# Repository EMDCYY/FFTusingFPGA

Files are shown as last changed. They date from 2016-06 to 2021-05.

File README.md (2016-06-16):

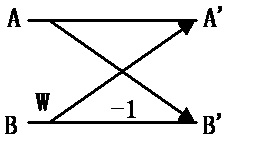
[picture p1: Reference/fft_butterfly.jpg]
  

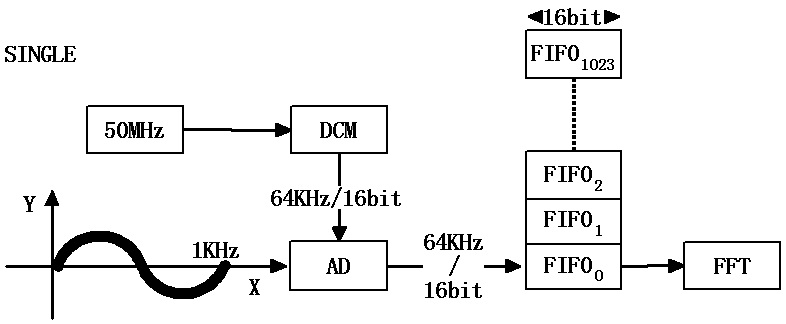
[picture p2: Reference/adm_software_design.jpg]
  

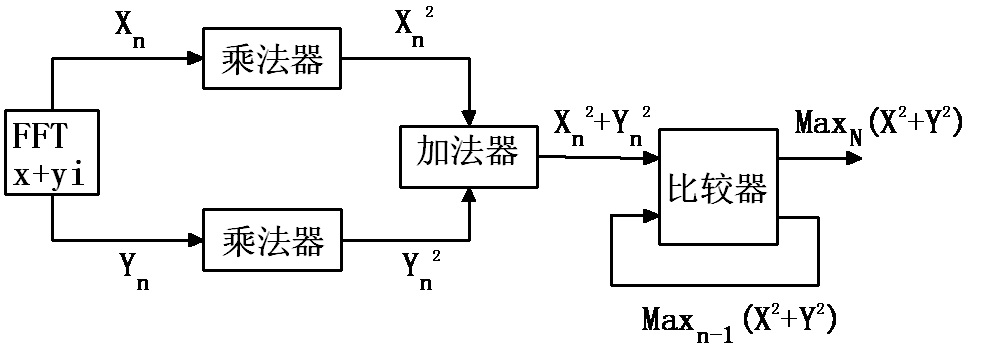
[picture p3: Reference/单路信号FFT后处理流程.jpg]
 

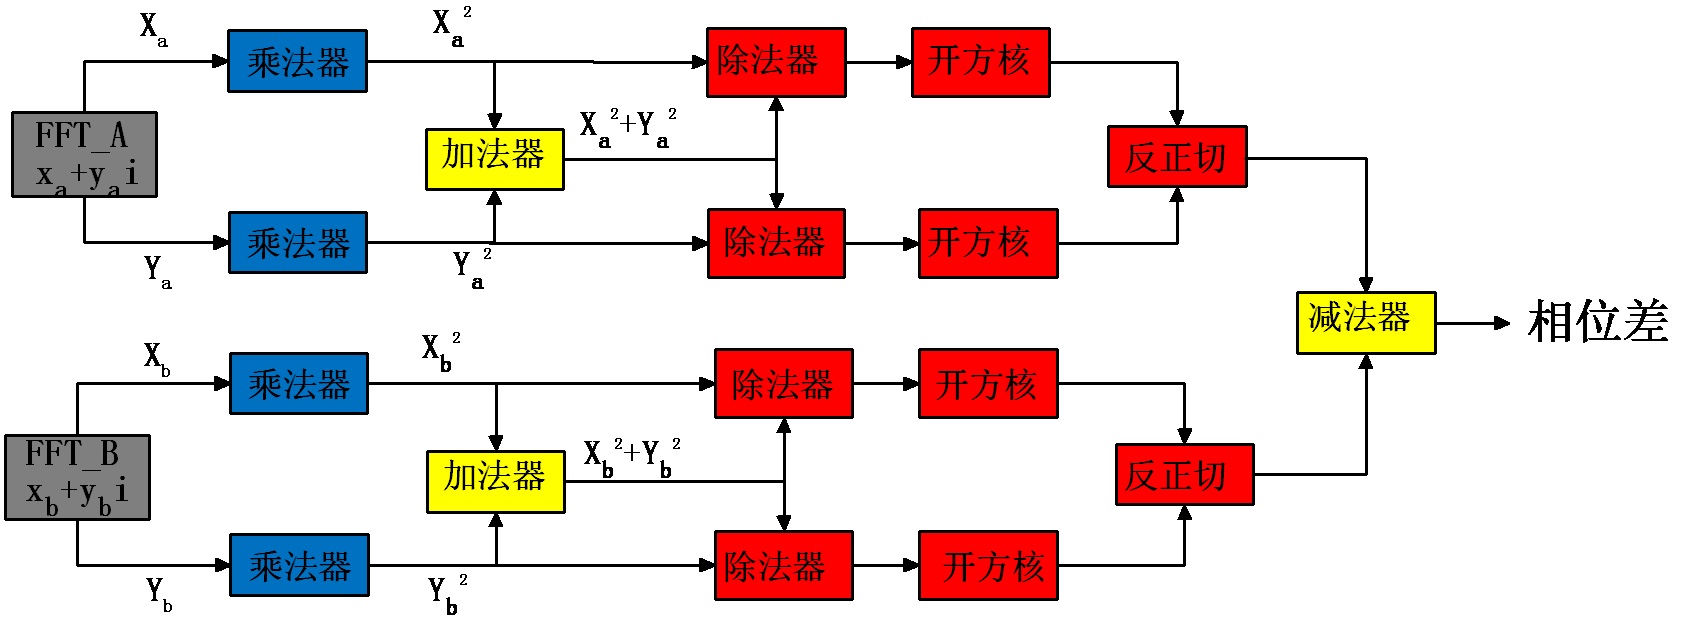
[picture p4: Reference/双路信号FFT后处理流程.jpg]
  

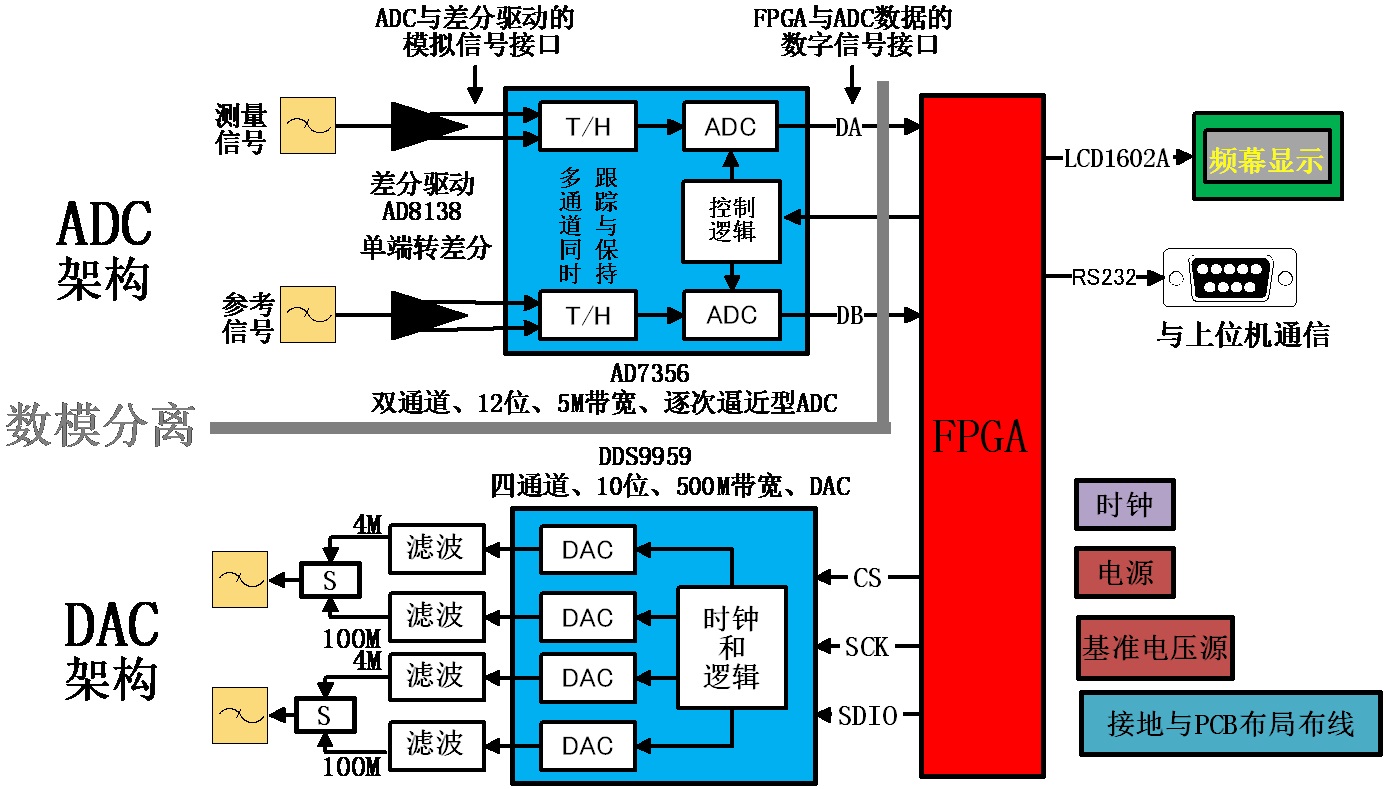
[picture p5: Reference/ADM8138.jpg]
   

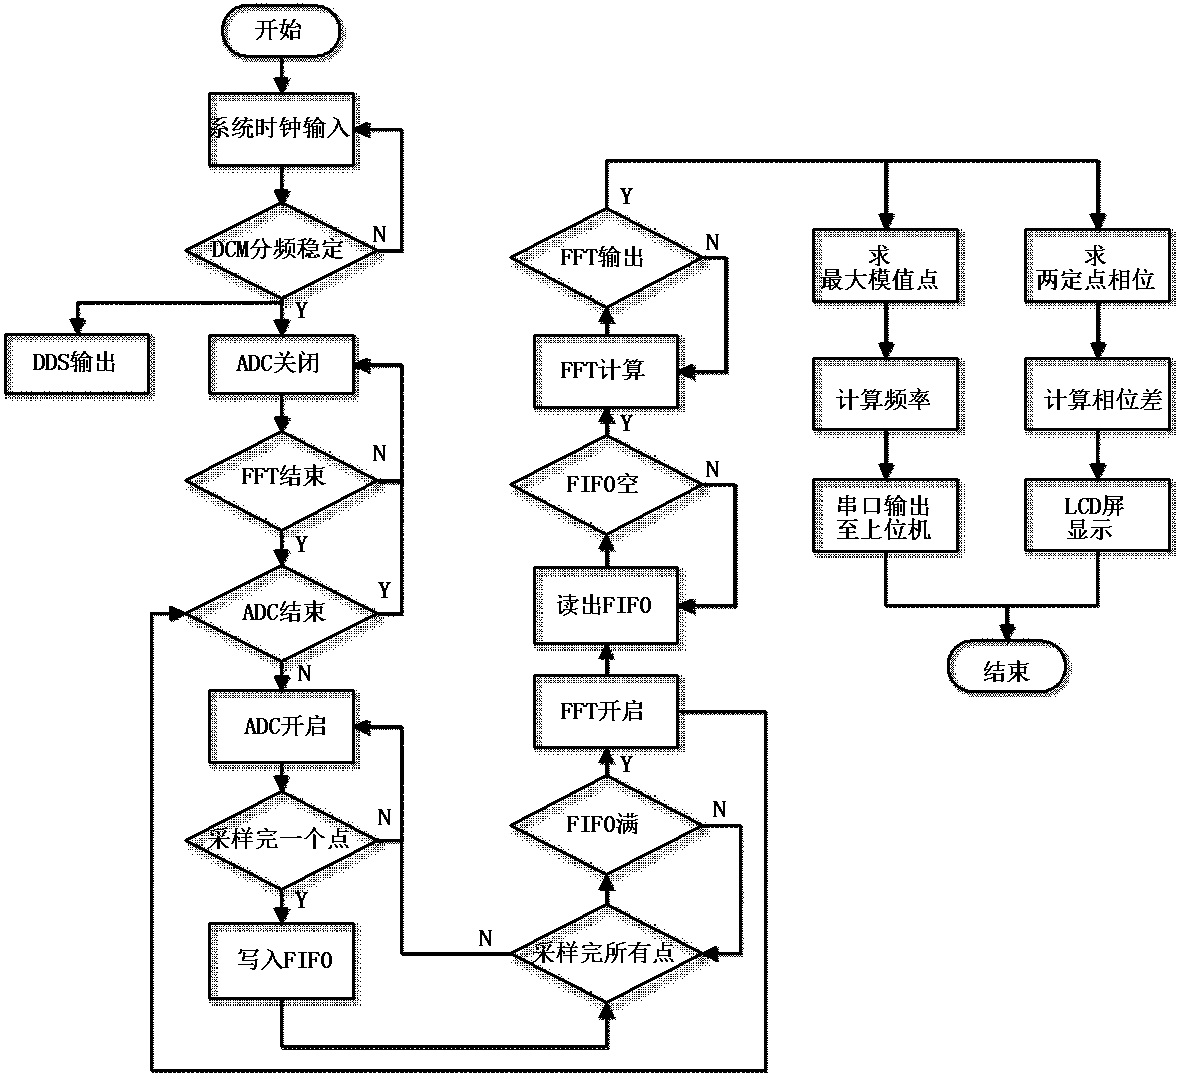
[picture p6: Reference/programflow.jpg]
  

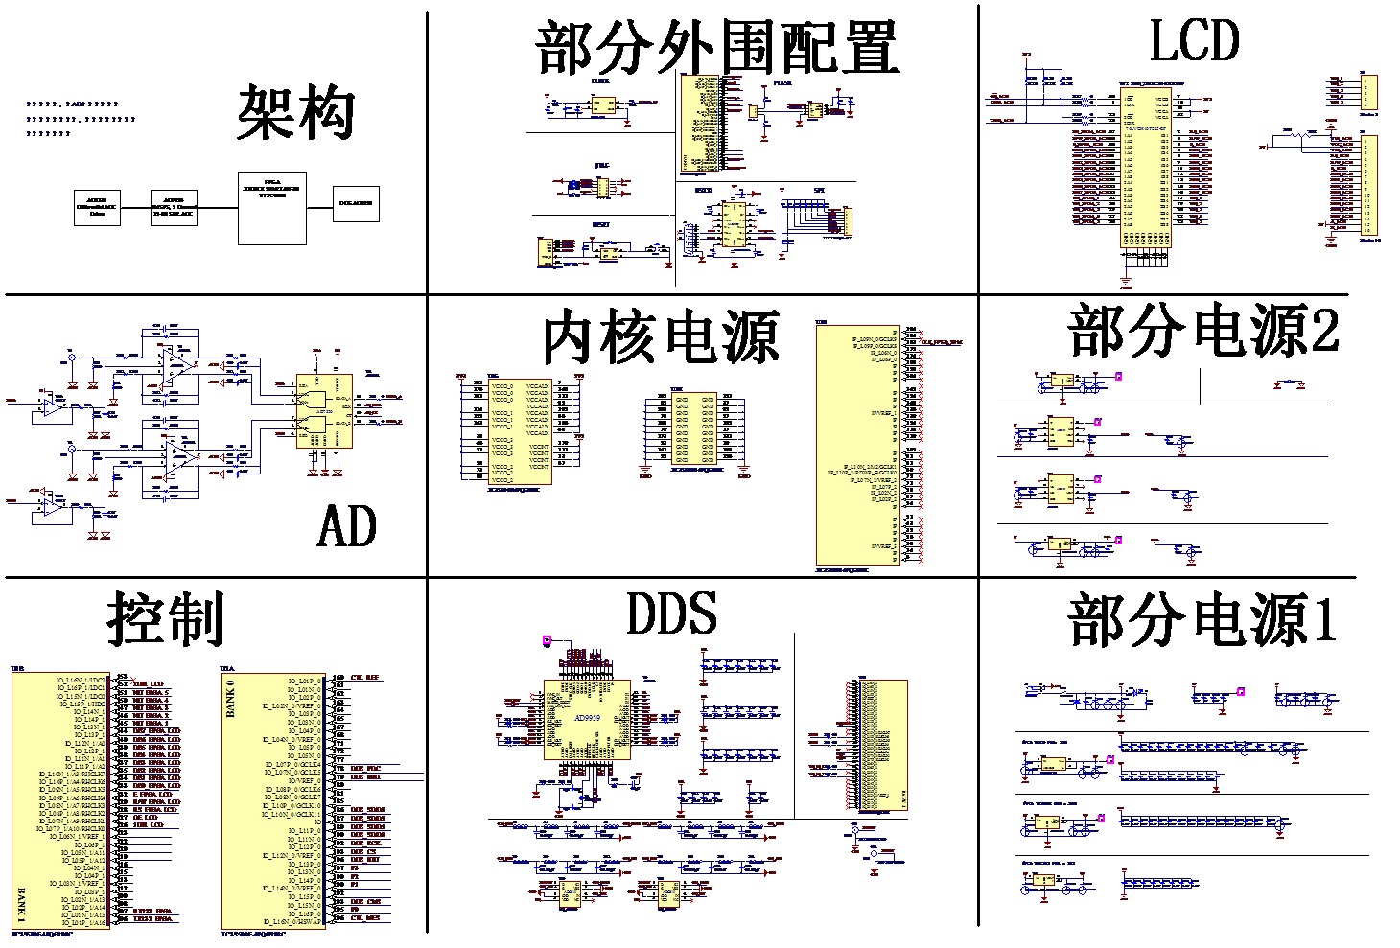
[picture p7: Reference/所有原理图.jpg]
  

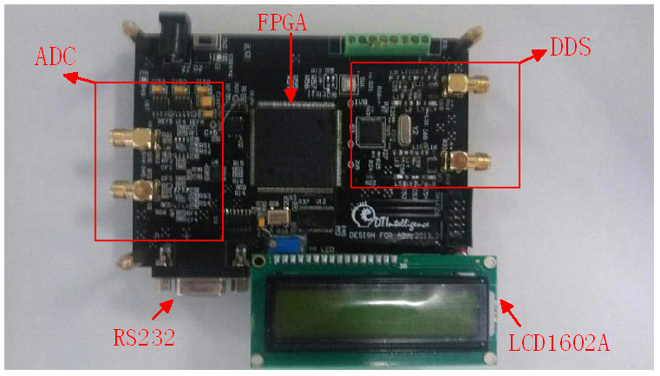
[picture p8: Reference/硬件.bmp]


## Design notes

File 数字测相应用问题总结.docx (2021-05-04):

# ADM数字测相技术问题归纳

刘鑫

2013.7.8

## 1. 功能概述

ADM数字测相由三部分功能组成：

①数字信号获取

②信号FFT处理

③求相位差计算

图1. ADM数字测相功能结构图

### 1.1 数字信号获取

数字信号获取的主要内容，是将两路正弦信号经AD同时采样转换成数字信号。本系统待测信号是两路频率为1KHz，峰-峰值为1Vp-p的双极性正弦波。通过MatLab仿真，若测相精度要达到千分之一个周期(1‰*2 π )，即测量绝对误差要在0.36°以内，需要选择转换速率在1.6M～3.2M之间、分辨率为10～12位的AD芯片。

#### 1.1.1 电路设计问题

这里选择AD7356是一款双12 bit、高速、低功耗的逐次逼近型（SAR）模数转换器（ADCC），采用2.5 V单电源供电，具有高达5 MSPS的吞吐率。该器件内置两个ADCC，各ADCC之前均配有一个低噪声、宽带宽采样保持电路，可处理110 MHz以上的输入频率。

但该器件是采用差分输入，其范围为共模±VRef/2。系统输入信号为单输入差分正弦信号，因此需要执行单端转差分转换。对AD7356进行差分驱动的理想方法是采用AD8138之类的差分放大器。该器件可以用作单端转差分放大器或差分转差分放大器。AD8138还能提供共模电平转换。实际电路图如下：

图2. 数字信号获取结构电路图

图2是参考AD器件生产商ADI公司提供文档“EVAL-AD7352/AD7356/AD7357”（见此附件16页）所绘。实际中，图2与文档参考电路图有区别，在于文档参考电路图差分驱动AD8138的V-端（1引脚）比图2多一个49R9端接电阻（如下图红线所标）。

图3. 文档参考电路图

问题1:

缺少的端接电阻对信号通过AD8138单端转差分的效果是否有影响？

#### 1.1.2 信号转换问题

两路正弦信号是由安捷伦脉冲函数发生器81150提供。设置参数如下：

①频率：1KHZ

②相位：1通道0°，2通道60°

③幅值：0.5V

④偏压：0V

两路信号如下图所示：

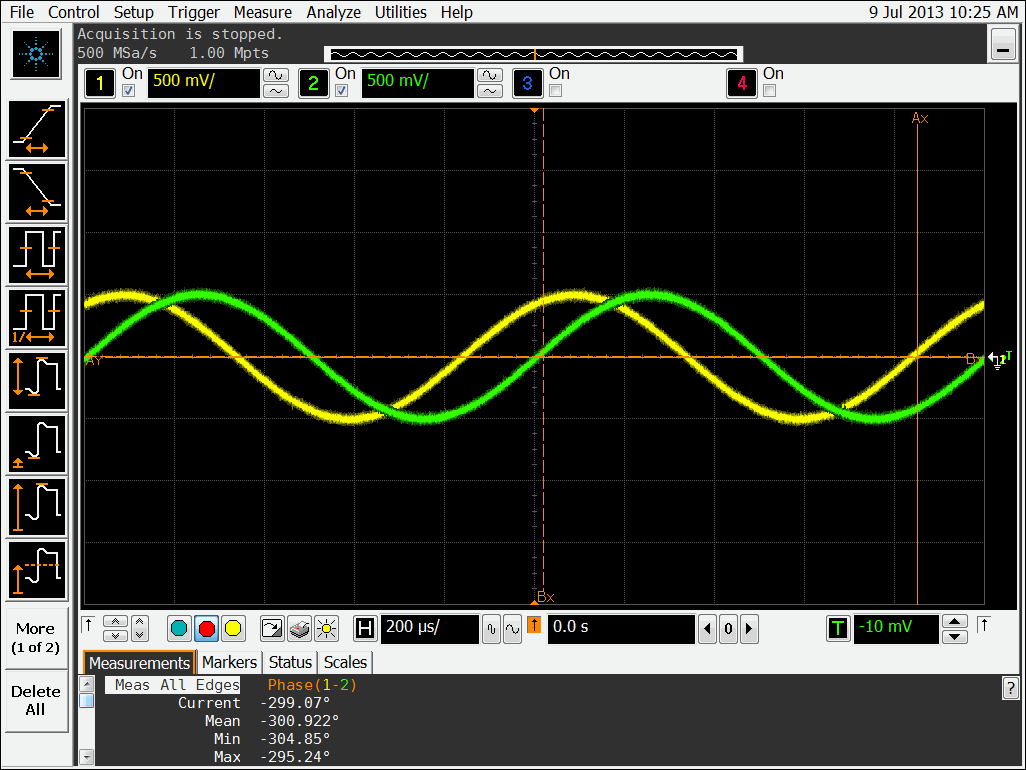
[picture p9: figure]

图4. 两路信号的设置

根据AD8138的参考使用效果,如下（亦见附件AD7356_cn第14页图20），

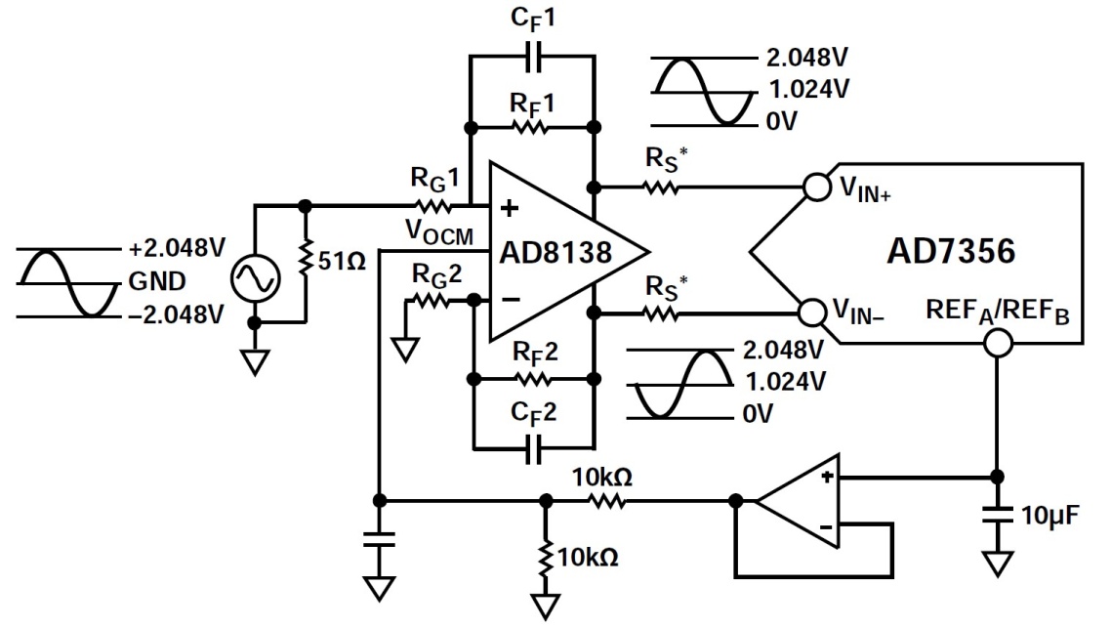
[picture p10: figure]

图5. AD8138参考使用效果

那么，1VP-P的正弦信号经过共模电平为1.25V的AD8138后，单端转差分的理论效果应如下图：

图6. 信号转变的理论效果

即，1VP-P正弦信号的转换效果：VP-P = 500mV，VOCM = 1.25V。

但实际的转换效果如下图，绿色为输入信号，其他为差分信号：

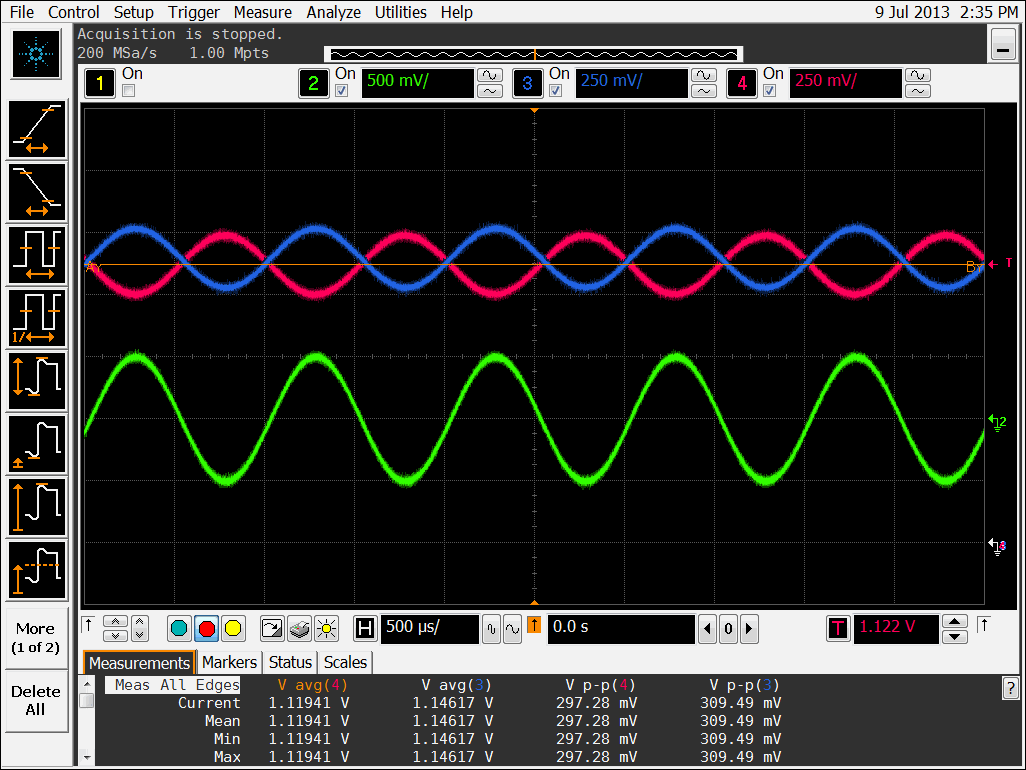
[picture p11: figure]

图7. 1VP-P正弦信号转换效果

1VP-P正弦信号的转换效果：VP-P = 300mV，VOCM = 1.13V。

峰峰值缩减是由于信号发生器输出端也有源电阻50Ω，再接与输入端接电阻49.9Ω分压，振幅缩减一半，交给AD8138处理的信号已变为500mVP-P，所以理论上，1VP-P正弦信号的转换效果应为VP-P = 250mV。

共模电平的降低或许与分压电阻R16、R17、R19、R20有关。虽然参考电路提供的分压电阻值是10KΩ，但在实际使用中发现，接地的10KΩ会与电路系统的阻值产生并联而降低阻值，所以实际中分压电阻选了较低的阻值50Ω。但高精度运放OP727的输入虽是2.5V，输出却是2.26V，经分压后成1.13V。

综上，既然输入端的端接电阻使得输入信号振幅减半，那么为了能使AD8138转换的是1VP-P正弦信号，就将信号发生器的信号源振幅增大一倍，即输入信号为2VP-P，转换结果如下图：

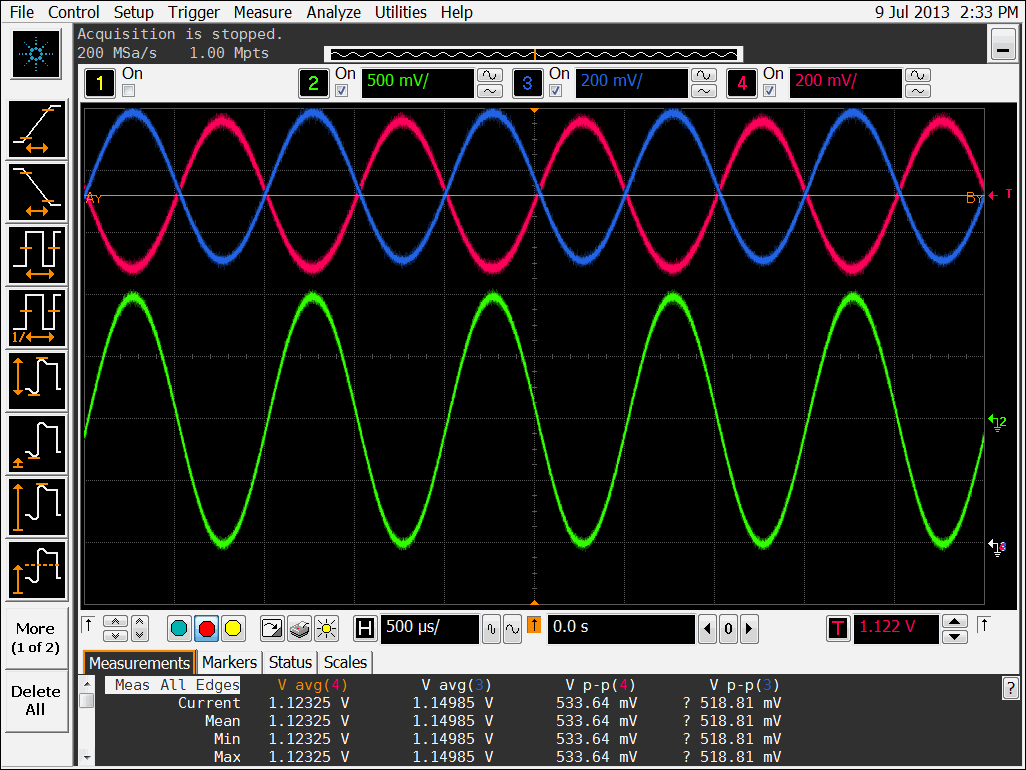
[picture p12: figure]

图8. 2VP-P正弦信号转换效果

2VP-P正弦信号的转换效果：VP-P = 0.5V，VOCM = 1.13V。符合理论值。

继续将信号发生器的输出信号振幅增大一倍，即输入信号为让4VP-P，转换结果如下图：

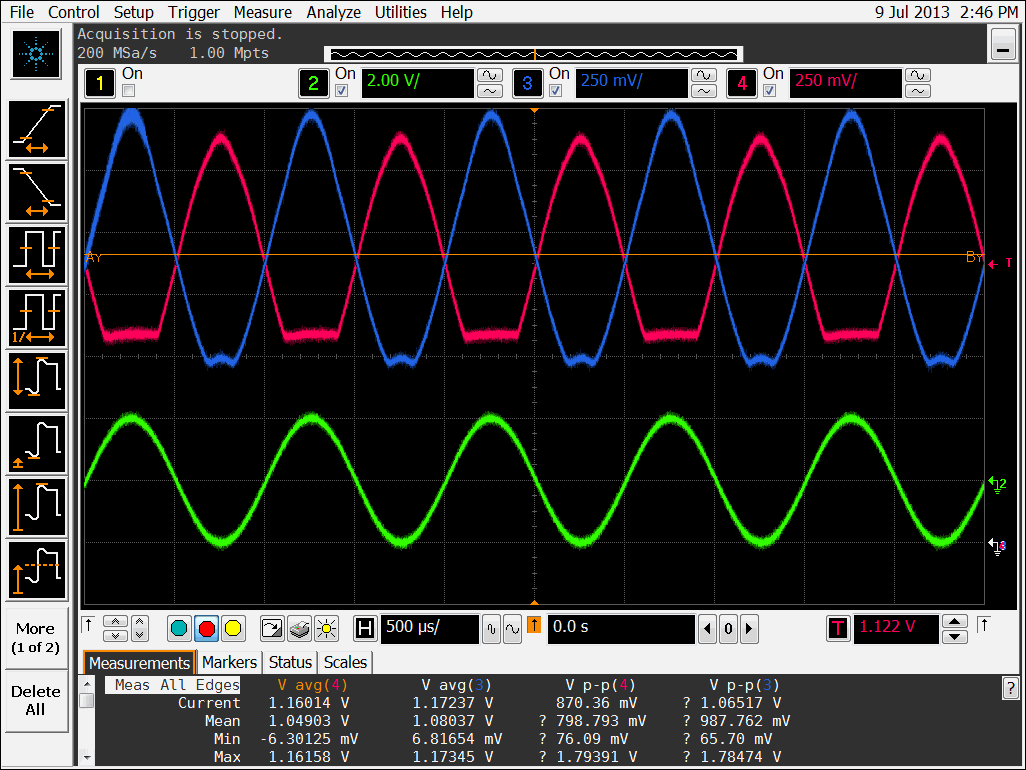
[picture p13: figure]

图9. 4VP-P正弦信号转换效果

之所以产生的差分信号在将近750mV~800mV之间出现截波，是因为我在设计时贪图单电源供电的方便，忽视了AD8138在单电源供电情况下的性能。图5中AD8138由±5V供电；当有单电源5V供电时，VOCM = 2.5V，输出电压最大摆幅是2.9V（见附件AD8138_cn第5页），即低电平截止电压为1V。

所以，虽然AD7356可以处理0V~2.5V电平范围内的信号，而且可以通过改变AD8138的反馈增益电阻RG1~4、RF1~4使得1VP-P输入信号转换为2.5VP-P差分信号，但由于本设计缺陷，使得差分信号只能局限1.5V~1V。

问题2：

实验证明，即使差分信号低电平被截止，FFT计算出该信号频率所对应的模值仍然最大。但是，低电平被截止是否影响求相位差，有何影响？下图白色波形为差分信号相减的结果。

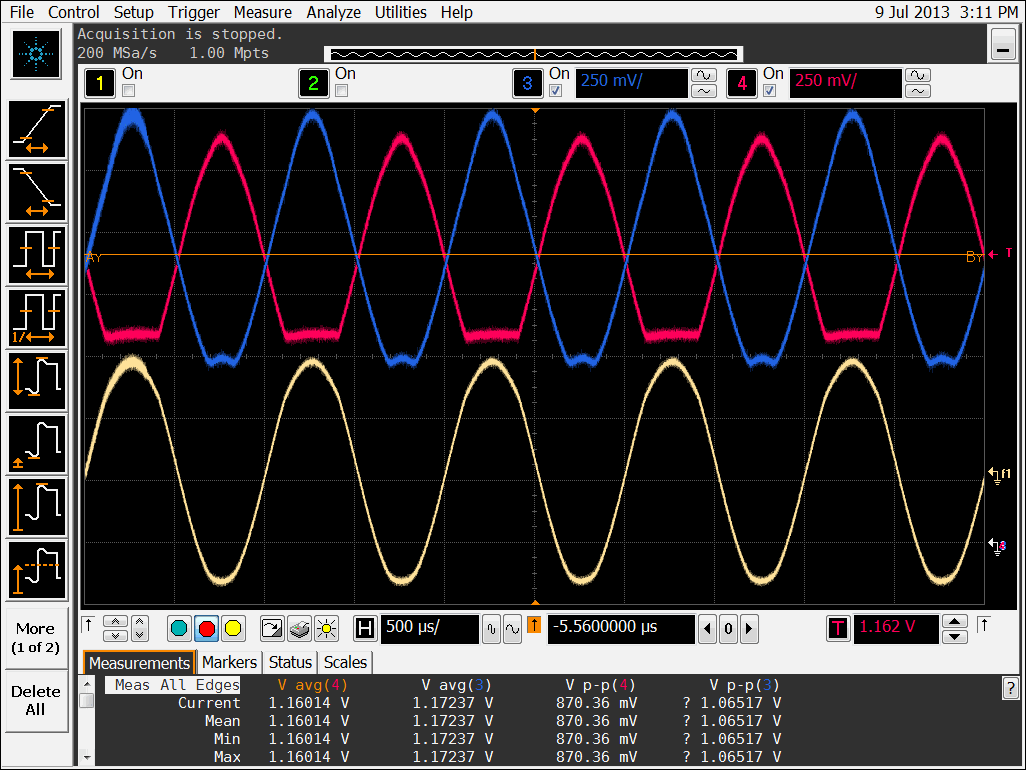
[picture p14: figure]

图10. 2VP-P正弦信号转换的差分信号相减

### 1.2 信号FFT处理

两路信号处理流程相同，且分别同时进行，如下图：

图11.信号处理流程图

FFT采用Xilinx提供的IP Core。通过串口将计算出的实部和虚部发送到上位机，用Excel处理，结果见附件。

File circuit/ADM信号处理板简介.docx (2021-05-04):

【产品名称】ADM信号处理平台

【产品功能】：

ADM信号处理平台采用XILINX SPARTEN-3E FPGA、高速AD7356和多通道直接数字频率合成器DDS9959作为平台芯片组。该平台可支持双路同时采样高达110 MHz的输入频率和四路同时输出高达500MHZ的标准正弦信号。

FPGA控制AD7356和DDS9959工作状态，并对采样信号进行FFT处理，将运算结果通过RS232或SPI传给上位机，或通过1602A显示。

# 【产品特色】

- 双路单端转差分高速运放驱动器
- 双路同时采样频率高达110MHZ
- 四路同时输出标准正弦波高达500MHZ
- 四路七阶巴特沃茨滤波器（默认分别为两组4MHZ和50MHZ）
- 具备RS232 \SPI \ 1602A

【主芯清单】：

# AD7356： 差分输入，双通道，同步采样，5 MSPS，12位SAR ADC

DDS9959：差分输出，四通道，同步输出，500MSPS，10位DAC

XC3S500E：XILINX FPGA，SPARTEN-3E FAMILY

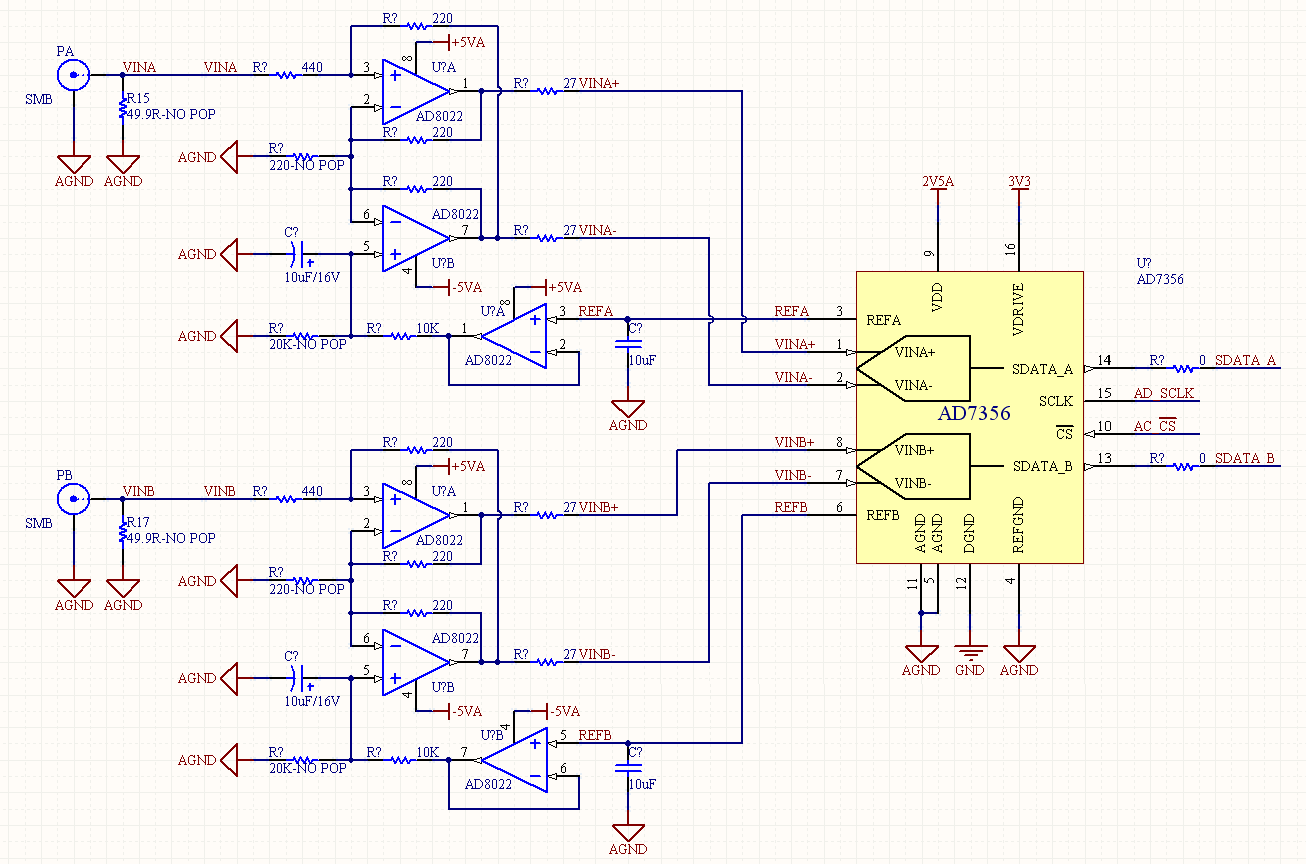
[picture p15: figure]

【FPGA电源】：

【AD7356电源】：

【数模隔离】

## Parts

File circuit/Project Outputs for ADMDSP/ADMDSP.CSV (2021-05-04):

Bill of Material for ADMDSP.PrjPCB
On 2013-3-4 at 20:25:52
Comment | Pattern | Quantity | Components
1V8 | MYTP | 1 | TP_9
2V5 | MYTP | 2 | TP_4, TP_8
3V3 | MYTP | 1 | TP_3
5V INPUT | IF_KLD-0202 | 1 | J2 | Low Voltage Power Supply Connector
5V | MYTP | 1 | TP_2
AD7356 | TSOP65P640X120-16N | 1 | U6 | Differential Input, Dual, Simultaneous Sampling, 5 MSPS, 12-Bit, SAR ADC
AD8138 | SOIC127P600X175-8N | 2 | U5, U8 | Low Distortion Differential ADC Driver
AD9959 | CP-56 | 1 | U9
ADR421 | SOIC127P600X175-8N | 2 | U16, U17 | Ultraprecision Low Noise, 2.048 V/2.500 V/ 3.00 V/5.00 V XFET? Voltage References
AS1117-2.5 | SOT223P700X180-4N | 1 | U14
BUS_74LVCH16T245-EP | TSSOP50P810X120-48N | 1 | U12
Cap Pol,100uF/25V,1210 | 1210[3528] | 7 | C86, C129, C131, C144, C146, C161, C169 | Polarized Capacitor (Radial)
Cap Pol,10uF/16V,1206 | 1206[3216] | 7 | C4, C150, C153, C157, C158, C167, C168 | Polarized Capacitor (Radial)
Cap Pol,10uF/25V,1206 | 1206[3216] | 14 | C62, C64, C66, C67, C72, C73, C74, C87, C88, C112, C130, C148, C155, C160 | Polarized Capacitor (Radial)
Cap Pol,150uF/15V,1206 | 7343 | 1 | C16 | Polarized Capacitor (Radial)
Cap Pol,22uF/25V,1210 | 1210[3528] | 1 | C145 | Polarized Capacitor (Radial)
Cap Pol,47uF/15V,1206 | 1210[3528] | 1 | C12 | Polarized Capacitor (Radial)
Cap,0.01nF/0603 | 1608[0603] - NoTopOverlay | 2 | C40, C48 | Capacitor
Cap,0.1uF/0603 | 1608[0603] | 78 | C1, C2, C3, C5, C6, C7, C8, C9, C10, C11, C13, C14, C15, C17, C45, C61, C63, C65, C68, C69, C70, C71, C75, C76, C77, C78, C79, C80, C81, C82, C83, C84, C85, C90, C91, C92, C93, C94, C95, C96, C97, C98, C99, C100, C113, C114, C115, C116, C117, C118, C119, C120, C121, C122, C123, C124, C125, C126, C127, C128, C136, C137, C138, C139, C140, C141, C142, C143, C147, C149, C151, C152, C154, C156, C159, C162, C163, C165 | Capacitor
Cap,0.1uF/0603 | 1608[0603] - NoTopOverlay | 27 | C18, C19, C20, C21, C22, C23, C24, C25, C26, C27, C28, C29, C30, C31, C32, C33, C34, C35, C36, C37, C38, C41, C42, C43, C44, C46, C47 | Capacitor
Cap,1.592nF/0603 | 1608[0603] - NoTopOverlay | 2 | C56, C59 | Capacitor
Cap,1uF/0805 | 2012[0805] | 2 | C164, C166 | Capacitor
Cap,39.693pF/0603 | 1608[0603] - NoTopOverlay | 4 | C49, C51, C52, C54 | Capacitor
Cap,39PF/0603 | 1608[0603] | 4 | CF1, CF2, CF3, CF4 | Capacitor
Cap,63.662pF/0603 | 1608[0603] - NoTopOverlay | 2 | C50, C53 | Capacitor
Cap,680pF/0603 | 1608[0603] - NoTopOverlay | 1 | C39 | Capacitor
Cap,992.315pF/0603 | 1608[0603] - NoTopOverlay | 4 | C55, C57, C58, C60 | Capacitor
D Connector 9 | DSUB1.385-2H9 | 1 | J1 | Receptacle Assembly, 9 Position, Right Angle
FAN1112 | SOT-223(FAN1112) | 1 | U15
Header 16 | HDR1X16 | 1 | P5 | Header, 16-Pin
Header 3 | HDR1X3 | 1 | P1 | Header, 3-Pin
Header 5 | HDR1X5 | 1 | P4 | Header, 5-Pin
Header 5X2 | 10Pin - JTAG | 1 | P2 | Header, 5-Pin, Dual row
Header 8 | 8PIN | 1 | P3 | Header, 8-Pin
Inductor,L0603,143.394nH | 2012[0805] - NoTopOverlay | 4 | L2, L3, L6, L7 | Inductor
Inductor,L0603,3.585uH | 2012[0805] - NoTopOverlay | 4 | L10, L11, L14, L15 | Inductor
Inductor,L0603,35.415nH | 2012[0805] - NoTopOverlay | 4 | L1, L4, L5, L8 | Inductor
Inductor,L0603,885.383nH | 2012[0805] - NoTopOverlay | 4 | L9, L12, L13, L16 | Inductor
LED | 2012[0805] - LED | 1 | D1
LM1117-1V8 | SOT223P700X180-4N | 1 | U19
LM1117-2V5 | SOT223P700X180-4N | 1 | U18
LM1117S-3.3 | TO-263-3SMD | 1 | U13
M25P80 | SOIC127P600X175-8N | 1 | U2
MAX3232CSE | NSO16 | 1 | U3
MAX811-EUS-T | SOT143 | 1 | U4
OP727 | SOIC127P600X175-8N | 1 | U7 | Precision Micropower Single-Supply Operational Amplifiers
P6SMBJ10A | SMBJ10A_DIOM4336X24N | 1 | D2 | Schottky Rectifier
REFA | MYTP | 1 | TP_6
REFB | MYTP | 1 | TP_7
Res Adj,20K | RES-adj | 1 | R41 | Tapped Resistor
Res,0R/0603 | 1608[0603] | 6 | R15, R18, R37, R38, R39, R40 | Resistor
Res,0R/0603 | 1608[0603] - NoTopOverlay | 4 | R54, R55, R56, R57 | Resistor
Res,0R/0805 | 1608[0603] - NoTopOverlay | 1 | R29 | Resistor
Res,0R/0805 | 2012[0805] | 1 | R43 | Resistor
Res,10K/0603,NoPoP | 1608[0603] | 2 | R52, R53 | Resistor
Res,10K/0603 | 1608[0603] | 14 | R5, R6, R14, R16, R17, R19, R20, R42, R46, R47, R48, R49, R50, R51 | Resistor
Res,10K/0805 | 1608[0603] | 2 | R12, R13 | Resistor
Res,1K/0805 | 1608[0603] | 4 | R8, R9, R10, R11 | Resistor
Res,1K/0805 | 1608[0603] - NoTopOverlay | 1 | R31 | Resistor
Res,2.2R/0805 | 1608[0603] | 2 | R2, R3 | Resistor
Res,33R/0603 | 1608[0603] | 4 | RS1, RS2, RS3, RS4 | Resistor
Res,4.7K/0603 | 1608[0603] | 3 | R34, R35, R36 | Resistor
Res,4.7K/0805 | 1608[0603] | 3 | R1, R4, R7 | Resistor
Res,49.9R/0805 | 1608[0603] - NoTopOverlay | 2 | R32, R33 | Resistor
Res,499R/0603 | 1608[0603] | 6 | RF1, RF2, RF3, RF4, RG1, RG4 | Resistor
Res,49R9/0603 | 1608[0603] | 2 | R44, R45 | Resistor
Res,50R/0805 | 1608[0603] - NoTopOverlay | 8 | R21, R22, R23, R24, R25, R26, R27, R28 | Resistor
Res,523R/0603 | 1608[0603] | 2 | RG3, RG6 | Resistor
Res,910R/0805 | 1608[0603] - NoTopOverlay | 1 | R30 | Resistor
SMB | SMB_V-RJ45 | 4 | CH1, CH2, V1, V2 | SMB Straight Connector
SW,EVQPLMA15_1 | PUSHBUTTONSW | 1 | SW1
SW_ADG619 | SOT23D | 2 | U10, U11 | Single SPDT Switches
SW-12D09 | SW_SD12D09 | 1 | SW2 | Single-Pole, Single-Throw Switch
TP_DDS_SYNC_CLK | MYTP | 1 | TP_1
XC3S500E-4PQG208C | PQG208_N | 1 | U1 | Spartan-3E 1.2V FPGA, 158 User I/Os, 208-Pin Pb-Free PQFP, Standard Performance, Commercial Grade
XTAL_25M | XTAL_DIP | 1 | Y2 | Crystal Oscillator
XTAL_50M | CRY_4Pin_50M | 1 | Y1

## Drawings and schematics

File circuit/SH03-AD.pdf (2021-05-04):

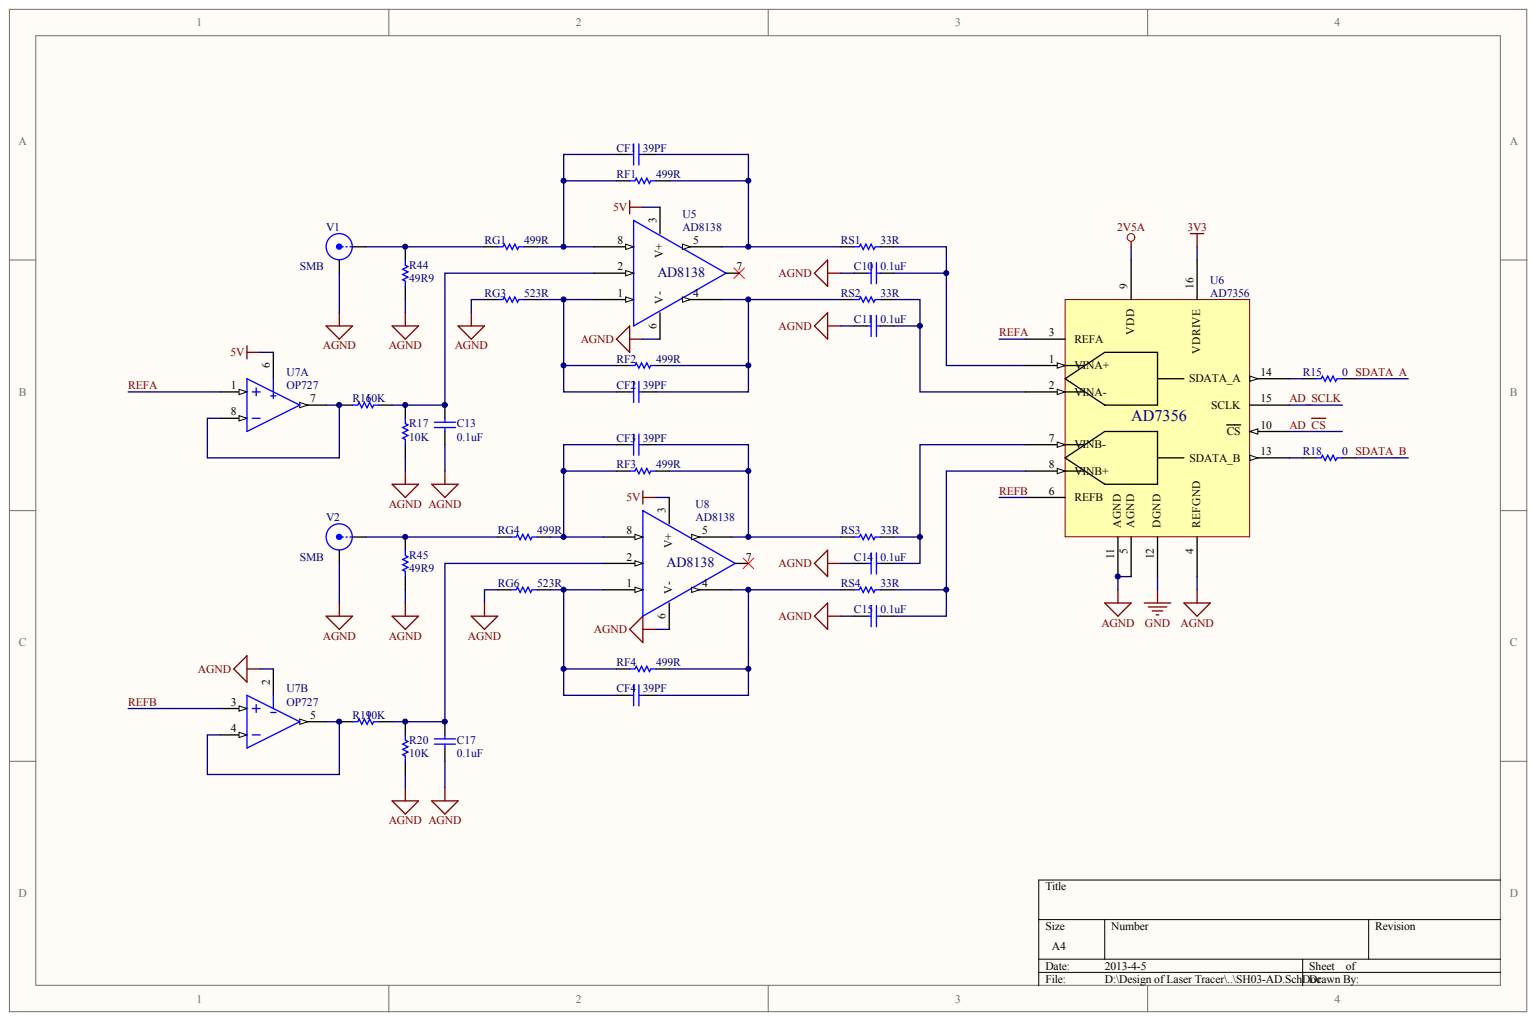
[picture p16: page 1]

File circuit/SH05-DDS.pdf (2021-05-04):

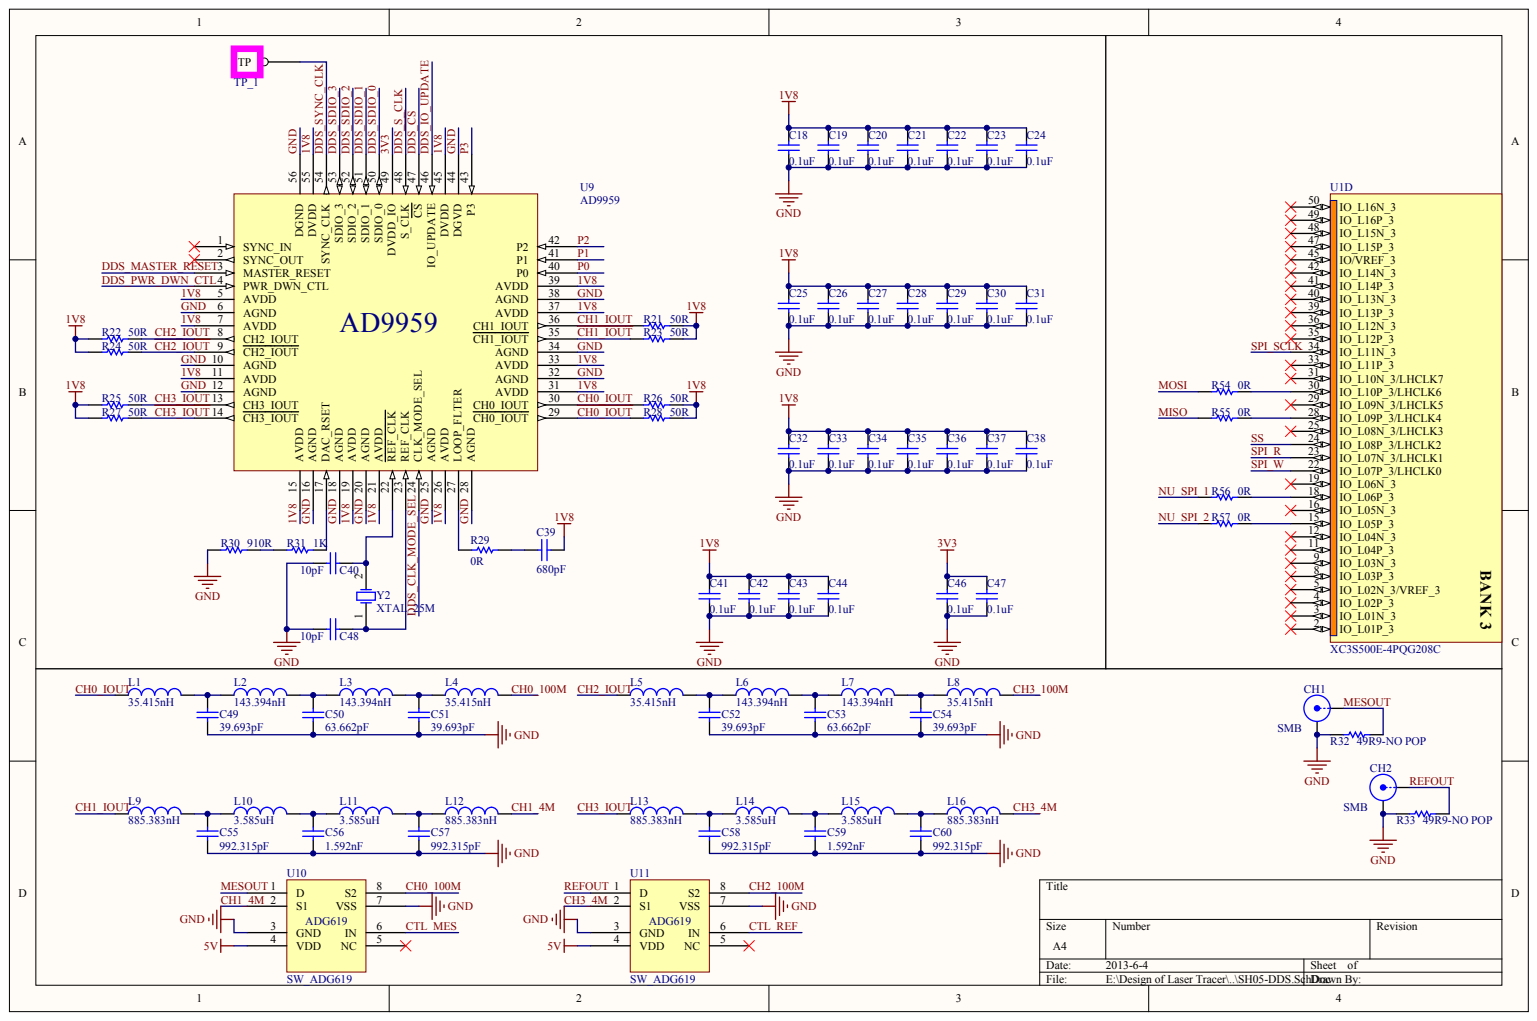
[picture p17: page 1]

P3 43 DGVD 44 DVDD 45 IO_UPDATE 46 CS 47 S_CLK 48 DVDD_IO 49 SDIO_0 50 SDIO_1 51 SDIO_2 52 SDIO_3 53 SYNC_CLK 54 DVDD 55 DGND 56

AGND 28 CH0_IOUT 29 CH0_IOUT 30 AVDD 31 AGND 32 AVDD 33 AGND 34 CH1_IOUT 35 CH1_IOUT 36 AVDD 37 AGND 38 AVDD 39 P0 40 P1 41 P2 42

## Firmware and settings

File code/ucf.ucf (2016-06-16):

NET "CLK_50M"  LOC = P183;
NET "SCLK"     LOC = P90;
NET "AD_CS"    LOC = P100;
NET "txd"      LOC = P106;
NET "SDA"      LOC = P94;
NET "SDB"      LOC = P98;
NET "OE"         LOC = p127;
NET "DIR1"       LOC = p126;
NET "DIR2"       LOC = p152;
NET "LCD_RS"     LOC = p128;
NET "LCD_RW"     LOC = p129;
NET "LCD_EN"     LOC = p132;
NET "LCD_DATA(0)"LOC = p133;
NET "LCD_DATA(1)"LOC = p134;
NET "LCD_DATA(2)"LOC = p135;
NET "LCD_DATA(3)"LOC = p137;
NET "LCD_DATA(4)"LOC = p138;
NET "LCD_DATA(5)"LOC = p139;
NET "LCD_DATA(6)"LOC = p140;
NET "LCD_DATA(7)"LOC = p144;
################################
net "dds_iou" loc = p196;
net "dds_cs" loc = p193;
net "dds_sck" loc = p192;
net "sdio0"   loc = p190;
net "sdio1"   loc = p189;
net "sdio2"   loc = p187;
net "sdio3"   loc = p186;
net "dds_mrt" loc = p179;
net "dds_pdc" loc = p178;
net "dds_cms" loc = p203;
net "p0" loc = p205;
net "p1" loc = p200;
net "p2" loc = p199;
net "p3" loc = p197;
net "ctrl_ref" loc = p160;
net "ctrl_mes" loc = p206;

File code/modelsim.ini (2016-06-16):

; Copyright 1991-2012 Mentor Graphics Corporation
;
; All Rights Reserved.
;
; THIS WORK CONTAINS TRADE SECRET AND PROPRIETARY INFORMATION WHICH IS THE PROPERTY OF 
; MENTOR GRAPHICS CORPORATION OR ITS LICENSORS AND IS SUBJECT TO LICENSE TERMS.
;   

[Library]
others = $MODEL_TECH/../modelsim.ini
;
; VITAL concerns:
;
; The library ieee contains (among other packages) the packages of the
; VITAL 2000 standard.  When a design uses VITAL 2000 exclusively, it should use
; the physical library ieee (recommended), or use the physical library
; vital2000, but not both.  The design can use logical library ieee and/or
; vital2000 as long as each of these maps to the same physical library, either
; ieee or vital2000.
;
; A design using the 1995 version of the VITAL packages, whether or not
; it also uses the 2000 version of the VITAL packages, must have logical library
; name ieee mapped to physical library vital1995.  (A design cannot use library
; vital1995 directly because some packages in this library use logical name ieee
; when referring to the other packages in the library.)  The design source
; should use logical name ieee when referring to any packages there except the
; VITAL 2000 packages.  Any VITAL 2000 present in the design must use logical
; name vital2000 (mapped to physical library vital2000) to refer to those
; packages.
; ieee = $MODEL_TECH/../vital1995
;
; For compatiblity with previous releases, logical library name vital2000 maps
; to library vital2000 (a different library than library ieee, containing the
; same packages).
; A design should not reference VITAL from both the ieee library and the
; vital2000 library because the vital packages are effectively different.
; A design that references both the ieee and vital2000 libraries must have
; both logical names ieee and vital2000 mapped to the same library, either of
; these:
;   $MODEL_TECH/../ieee
;   $MODEL_TECH/../vital2000
;
;vhdl_psl_checkers = $MODEL_TECH/../vhdl_psl_checkers       // Source files only for this release
;verilog_psl_checkers = $MODEL_TECH/../verilog_psl_checkers // Source files only for this release
;mvc_lib = $MODEL_TECH/../mvc_lib

unimacro = C:\Xilinx\13.1\ISE_DS\ISE\vhdl\mti_se\10.1a\nt/unimacro
unisim = C:\Xilinx\13.1\ISE_DS\ISE\vhdl\mti_se\10.1a\nt/unisim
unimacro_ver = c:\Xilinx\13.1\ISE_DS\ISE\verilog\mti_se\10.1a\nt/unimacro_ver
unisims_ver = c:\Xilinx\13.1\ISE_DS\ISE\verilog\mti_se\10.1a\nt/unisims_ver
simprim = C:\Xilinx\13.1\ISE_DS\ISE\vhdl\mti_se\10.1a\nt/simprim
simprims_ver = c:\Xilinx\13.1\ISE_DS\ISE\verilog\mti_se\10.1a\nt/simprims_ver
xilinxcorelib = C:\Xilinx\13.1\ISE_DS\ISE\vhdl\mti_se\10.1a\nt/xilinxcorelib
xilinxcorelib_ver = c:\Xilinx\13.1\ISE_DS\ISE\verilog\mti_se\10.1a\nt/xilinxcorelib_ver
cdn_axi4_lite_master_bfm_wrap_v1_00_a = c:\Xilinx\13.1\ISE_DS\ISE\mti_se\10.1a\nt/edk/cdn_axi4_lite_master_bfm_wrap_v1_00_a
cdn_axi4_lite_slave_bfm_wrap_v1_00_a = c:\Xilinx\13.1\ISE_DS\ISE\mti_se\10.1a\nt/edk/cdn_axi4_lite_slave_bfm_wrap_v1_00_a
cdn_axi4_master_bfm_wrap_v1_00_a = c:\Xilinx\13.1\ISE_DS\ISE\mti_se\10.1a\nt/edk/cdn_axi4_master_bfm_wrap_v1_00_a
cdn_axi4_slave_bfm_wrap_v1_00_a = c:\Xilinx\13.1\ISE_DS\ISE\mti_se\10.1a\nt/edk/cdn_axi4_slave_bfm_wrap_v1_00_a
common_v1_00_a = c:\Xilinx\13.1\ISE_DS\ISE\mti_se\10.1a\nt/edk/common_v1_00_a
apu_fpu_v3_10_a = c:\Xilinx\13.1\ISE_DS\ISE\mti_se\10.1a\nt/edk/apu_fpu_v3_10_a
apu_fpu_virtex5_v1_01_a = c:\Xilinx\13.1\ISE_DS\ISE\mti_se\10.1a\nt/edk/apu_fpu_virtex5_v1_01_a
axi2axi_connector_v1_00_a = c:\Xilinx\13.1\ISE_DS\ISE\mti_se\10.1a\nt/edk/axi2axi_connector_v1_00_a
axi_7series_ddrx_v1_00_a = c:\Xilinx\13.1\ISE_DS\ISE\mti_se\10.1a\nt/edk/axi_7series_ddrx_v1_00_a
proc_common_v3_00_a = c:\Xilinx\13.1\ISE_DS\ISE\mti_se\10.1a\nt/edk/proc_common_v3_00_a
axi_ahblite_bridge_v1_00_a = c:\Xilinx\13.1\ISE_DS\ISE\mti_se\10.1a\nt/edk/axi_ahblite_bridge_v1_00_a
axi_apb_bridge_v1_00_a = c:\Xilinx\13.1\ISE_DS\ISE\mti_se\10.1a\nt/edk/axi_apb_bridge_v1_00_a
edk = c:\Xilinx\13.1\ISE_DS\ISE\mti_se\10.1a\nt/edk
axi_bram_ctrl_v1_02_a = c:\Xilinx\13.1\ISE_DS\ISE\mti_se\10.1a\nt/edk/axi_bram_ctrl_v1_02_a
lib_common_v1_00_a = c:\Xilinx\13.1\ISE_DS\ISE\mti_se\10.1a\nt/edk/lib_common_v1_00_a
axi_lite_ipif_v1_01_a = c:\Xilinx\13.1\ISE_DS\ISE\mti_se\10.1a\nt/edk/axi_lite_ipif_v1_01_a
axi_can_v1_02_a = c:\Xilinx\13.1\ISE_DS\ISE\mti_se\10.1a\nt/edk/axi_can_v1_02_a
axi_datamover_v1_00_a = c:\Xilinx\13.1\ISE_DS\ISE\mti_se\10.1a\nt/edk/axi_datamover_v1_00_a
axi_sg_v1_00_a = c:\Xilinx\13.1\ISE_DS\ISE\mti_se\10.1a\nt/edk/axi_sg_v1_00_a
axi_sg_v2_00_a = c:\Xilinx\13.1\ISE_DS\ISE\mti_se\10.1a\nt/edk/axi_sg_v2_00_a
axi_datamover_v2_00_a = c:\Xilinx\13.1\ISE_DS\ISE\mti_se\10.1a\nt/edk/axi_datamover_v2_00_a
axi_sg_v2_01_a = c:\Xilinx\13.1\ISE_DS\ISE\mti_se\10.1a\nt/edk/axi_sg_v2_01_a
axi_cdma_v3_00_a = c:\Xilinx\13.1\ISE_DS\ISE\mti_se\10.1a\nt/edk/axi_cdma_v3_00_a
axi_dma_v3_00_a = c:\Xilinx\13.1\ISE_DS\ISE\mti_se\10.1a\nt/edk/axi_dma_v3_00_a
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

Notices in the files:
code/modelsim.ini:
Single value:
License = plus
